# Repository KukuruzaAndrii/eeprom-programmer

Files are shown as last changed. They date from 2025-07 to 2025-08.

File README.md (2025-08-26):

## PCB design
Done in KiCad 9.0

### Scheme
[Scheme](pcb/v1/scheme/eeprom-programmer.pdf)

### PCB
Two versions of PCB placed in repo: regular and with rounded tracks.
Rounded tracks done with [mitxela plugin](https://github.com/mitxela/kicad-round-tracks)

### BOM
[Interactive BOM list](pcb/v1/bom/ibom.html)

### Gergers
For [regular pcb](pcb/v1/gerbers) and [rounded pcb](pcb/v1/gerbers-rounded)

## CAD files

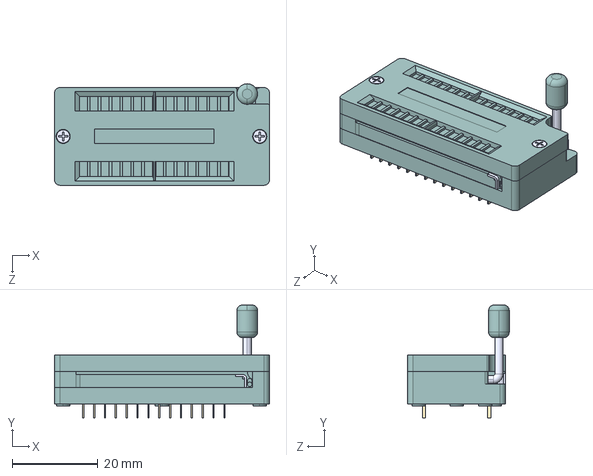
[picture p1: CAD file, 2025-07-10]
pcb/v1/Components/228_1277_00_0602J/228-1277-00-0602J.STEP
50.3 x 26.4 x 23.7 mm

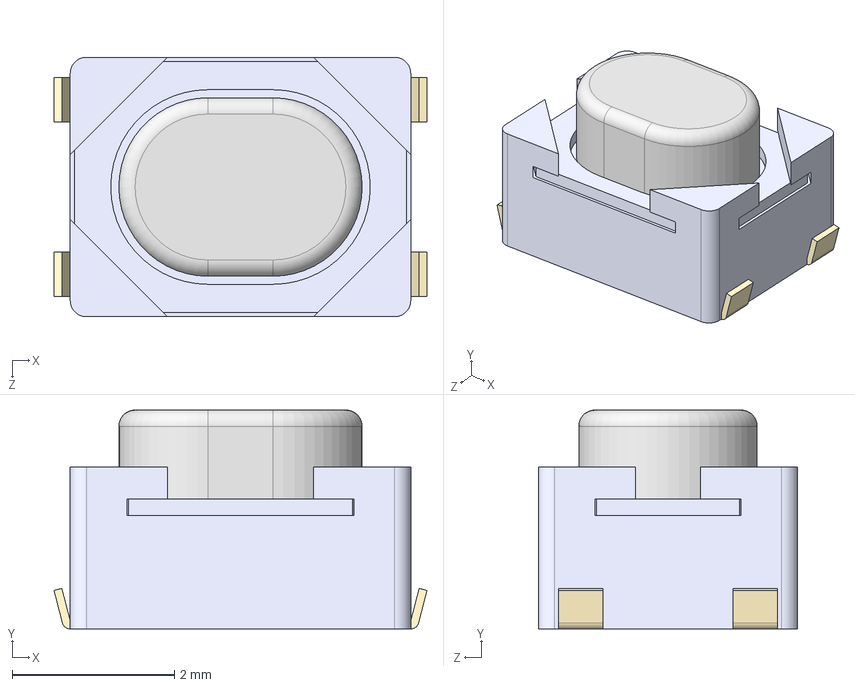
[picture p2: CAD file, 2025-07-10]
pcb/v1/Components/PTS810SJM250SMTR_LFS/PTS810SJM250SMTR LFS.STEP
4.60 x 2.70 x 3.20 mm

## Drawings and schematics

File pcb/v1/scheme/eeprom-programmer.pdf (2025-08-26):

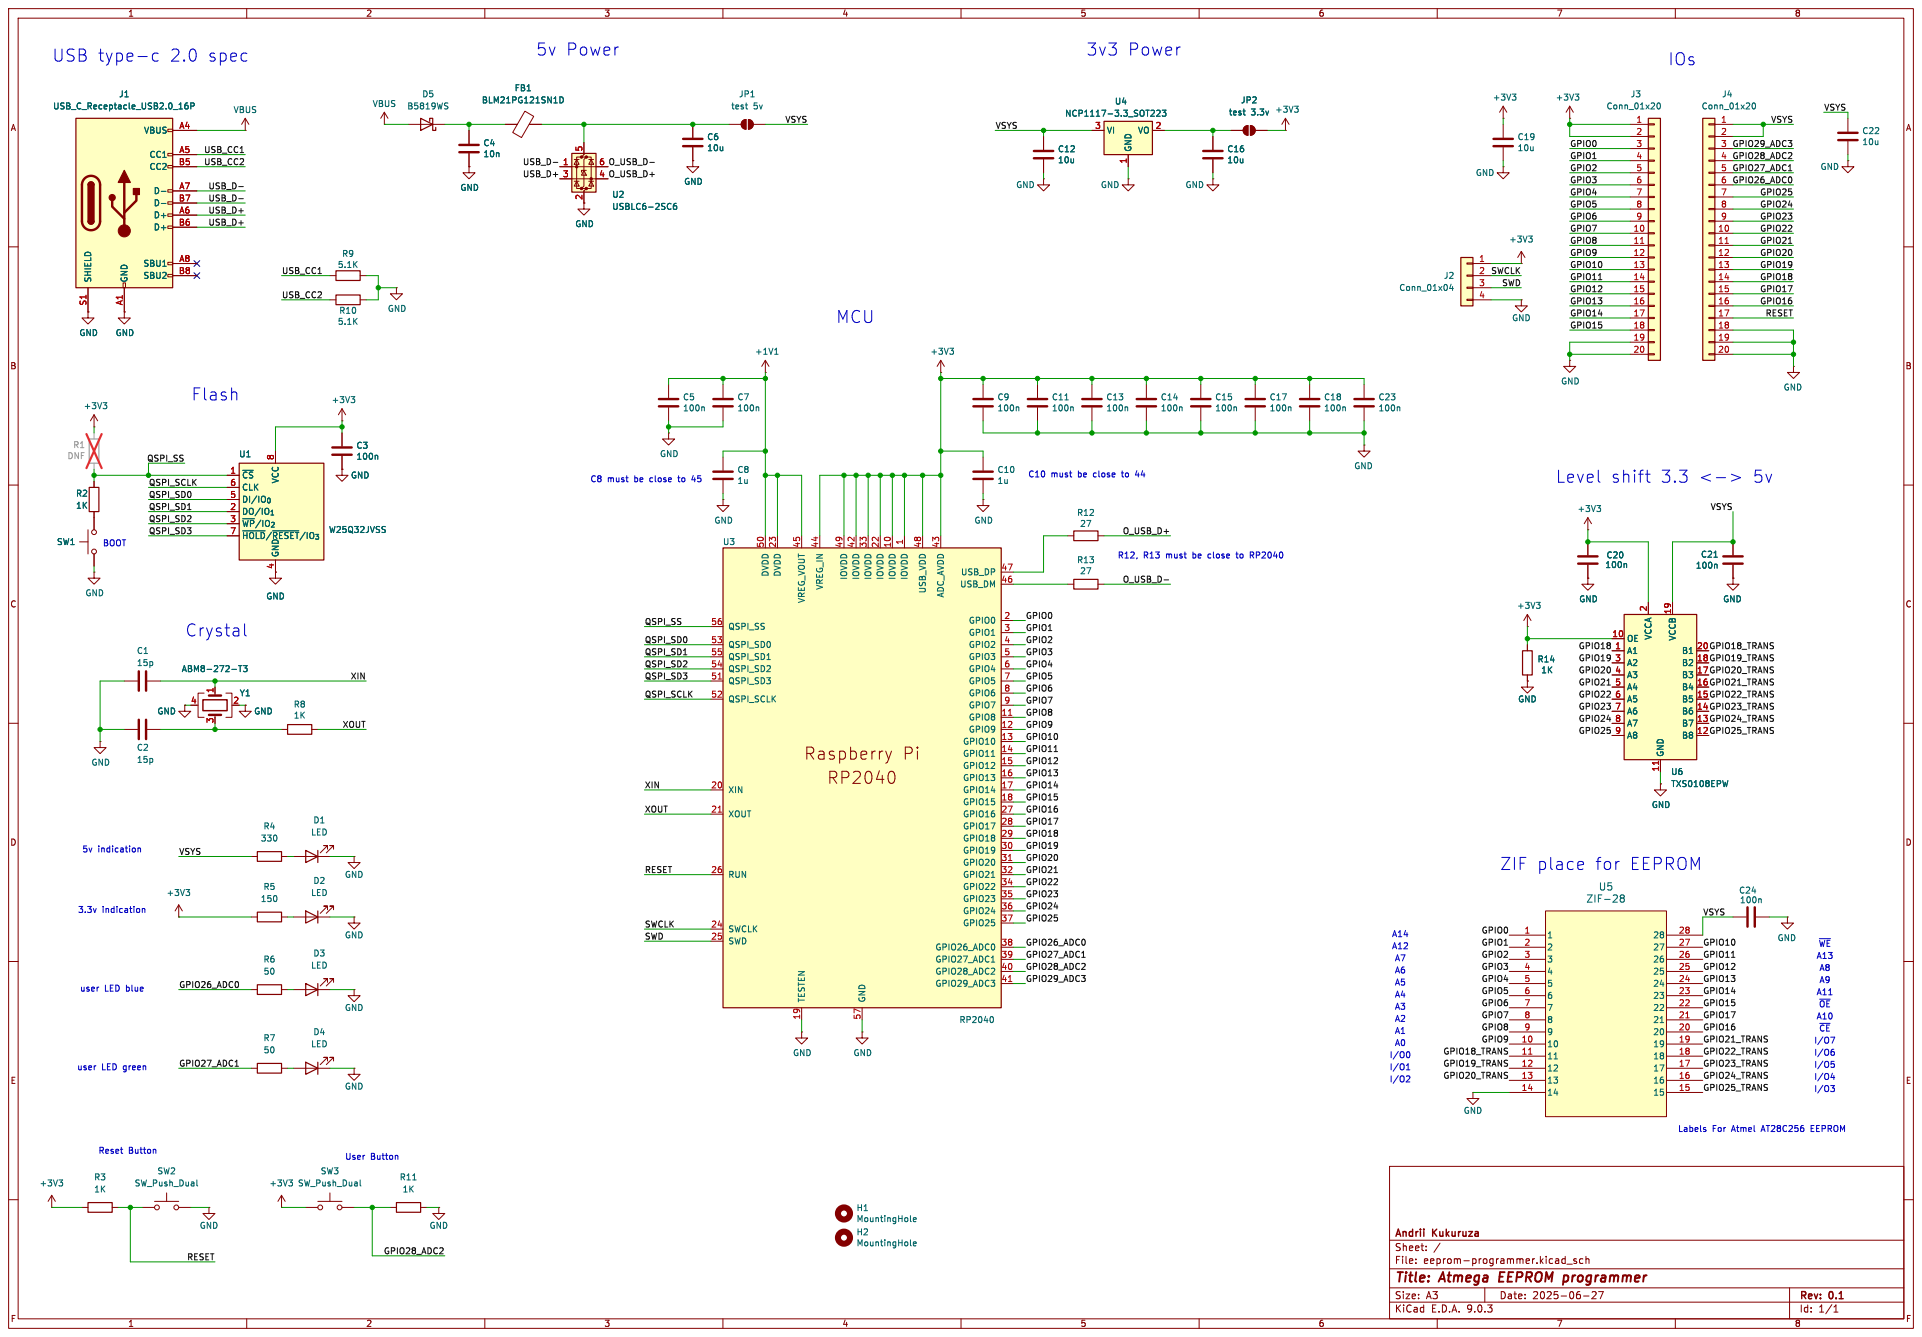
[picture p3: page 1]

3 GND GND GND GND
Crystal

I/O1 User Button Reset Button

Labels For Atmel AT28C256 EEPROM

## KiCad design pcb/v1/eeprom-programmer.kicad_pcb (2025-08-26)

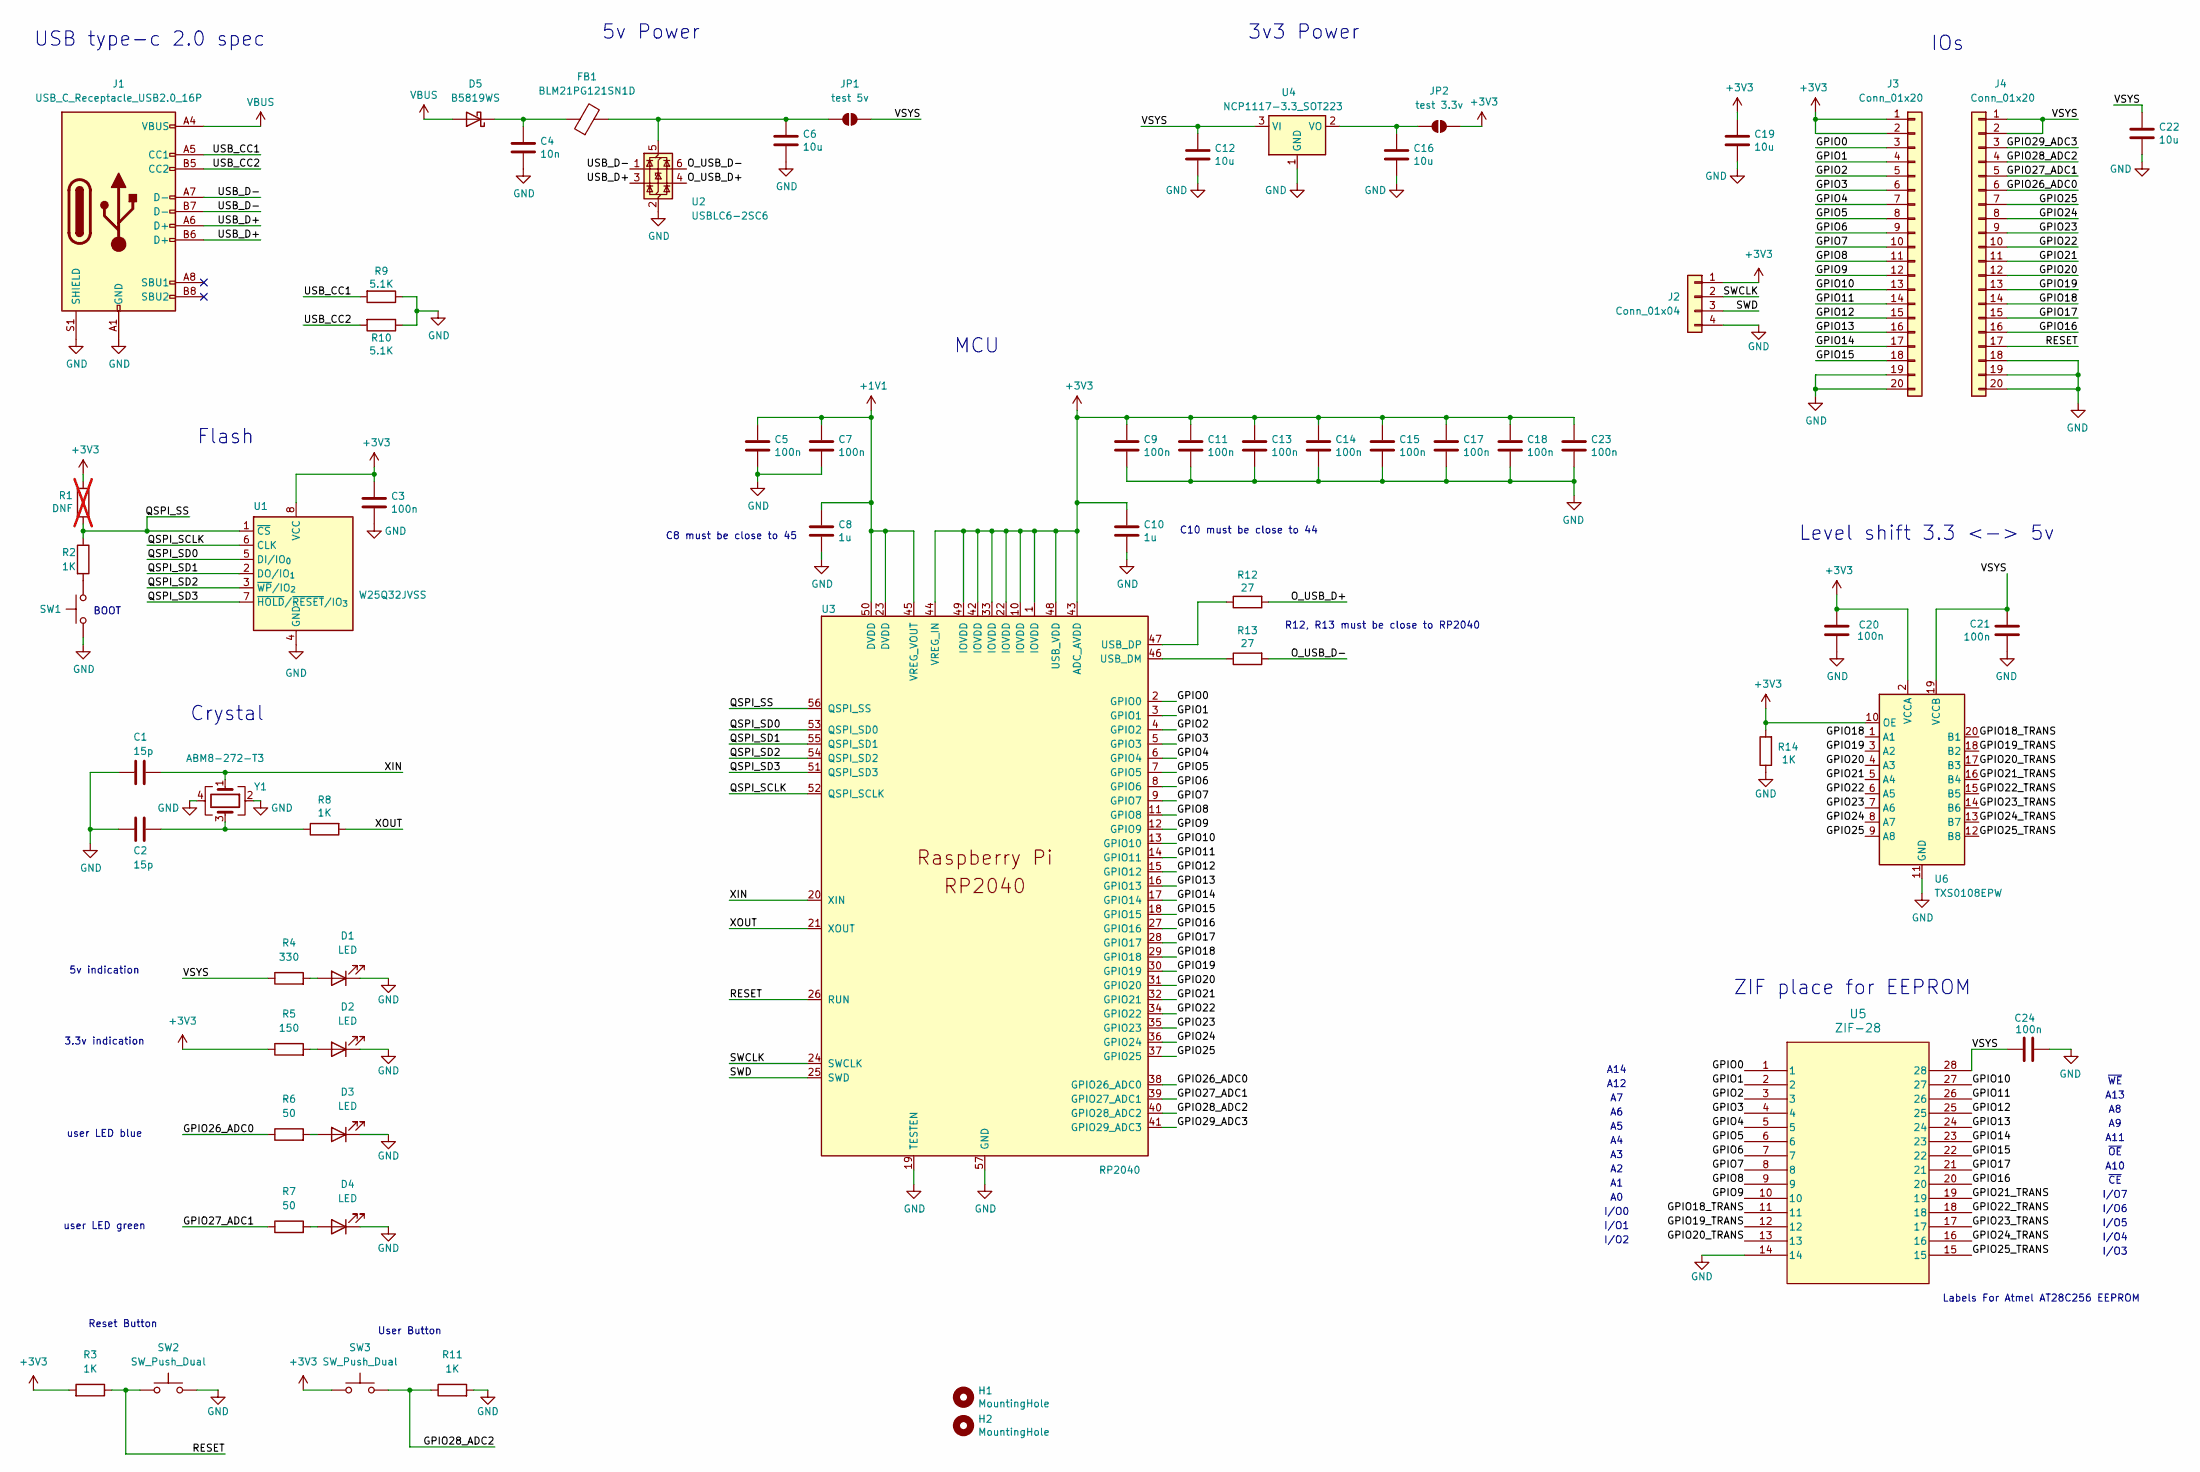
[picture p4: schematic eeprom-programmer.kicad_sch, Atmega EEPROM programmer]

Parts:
C1, C2: 15p; C_0603_1608Metric_Pad1.08x0.95mm_HandSolder
C3, C5, C7, C9, C11, C13, C14, C15, C17, C18, C20, C21, C23, C24: 100n; C_0603_1608Metric_Pad1.08x0.95mm_HandSolder
C4: 10n; C_0603_1608Metric_Pad1.08x0.95mm_HandSolder
C6, C12, C16, C19, C22: 10u; C_0603_1608Metric_Pad1.08x0.95mm_HandSolder
C8, C10: 1u; C_0603_1608Metric_Pad1.08x0.95mm_HandSolder
D1, D2, D3, D4: LED; LED_0603_1608Metric_Pad1.05x0.95mm_HandSolder
D5: B5819WS; D_SOD-323_HandSoldering
FB1: BLM21PG121SN1D; L_0805_2012Metric_Pad1.05x1.20mm_HandSolder
H1, H2: MountingHole; MountingHole_2.7mm_M2.5
J1: USB_C_Receptacle_USB2.0_16P; USB_C_Receptacle_GCT_USB4105-xx-A_16P_TopMnt_Horizontal
J2: Conn_01x04; PinHeader_1x04_P2.54mm_Vertical
J3, J4: Conn_01x20; PinHeader_1x20_P2.54mm_Vertical
JP1: test 5v; SolderJumper-2_P1.3mm_Open_RoundedPad1.0x1.5mm
JP2: test 3.3v; SolderJumper-2_P1.3mm_Open_RoundedPad1.0x1.5mm
R1: DNF; R_0603_1608Metric_Pad0.98x0.95mm_HandSolder; not fitted
R2, R3, R8, R11, R14: 1K; R_0603_1608Metric_Pad0.98x0.95mm_HandSolder
R4: 330; R_0603_1608Metric_Pad0.98x0.95mm_HandSolder
R5: 150; R_0603_1608Metric_Pad0.98x0.95mm_HandSolder
R6, R7: 50; R_0603_1608Metric_Pad0.98x0.95mm_HandSolder
R9, R10: 5.1K; R_0603_1608Metric_Pad0.98x0.95mm_HandSolder
R12, R13: 27; R_0603_1608Metric_Pad0.98x0.95mm_HandSolder
SW1, SW2, SW3: SW_Push_Dual; SW_SPST_PTS810
U1: W25Q32JVSS; SOIC-8_5.3x5.3mm_P1.27mm
U2: USBLC6-2SC6; SOT-23-6_Handsoldering
U3: RP2040; RP2040-QFN-56
U4: NCP1117-3.3_SOT223; SOT-223-3_TabPin2
U5: ZIF-28; DIP_Socket-28_W11.9_W12.7_W15.24_W17.78_W18.5_3M_228-1277-0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
U6: TXS0108EPW; TSSOP-20_4.4x6.5mm_P0.65mm
Y1: ABM8-272-T3; Crystal_SMD_Abracon_ABM8G-4Pin_3.2x2.5mm

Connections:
+1V1: C5.1, C7.1, C8.1, U3.23 (DVDD), U3.45 (VREG_VOUT), U3.50 (DVDD)
+3V3: C3.1, C9.1, C10.1, C11.1, C13.1, C14.1, C15.1, C17.1, C18.1, C19.1, C20.2, C23.1, J2.1, J3.1, J3.2, JP2.2 (B), R1.1, R3.2, R5.1, R14.2, SW3.1, U1.8 (VCC), U3.1 (IOVDD), U3.10 (IOVDD), U3.22 (IOVDD), U3.33 (IOVDD), U3.42 (IOVDD), U3.43 (ADC_AVDD), U3.44 (VREG_IN), U3.48 (USB_VDD), U3.49 (IOVDD), U6.2 (VCCA), U6.10 (OE)
/GPIO0: J3.3, U3.2 (GPIO0), U5.1
/GPIO1: J3.4, U3.3 (GPIO1), U5.2
/GPIO2: J3.5, U3.4 (GPIO2), U5.3
/GPIO3: J3.6, U3.5 (GPIO3), U5.4
/GPIO4: J3.7, U3.6 (GPIO4), U5.5
/GPIO5: J3.8, U3.7 (GPIO5), U5.6
/GPIO6: J3.9, U3.8 (GPIO6), U5.7
/GPIO7: J3.10, U3.9 (GPIO7), U5.8
/GPIO8: J3.11, U3.11 (GPIO8), U5.9
/GPIO9: J3.12, U3.12 (GPIO9), U5.10
/GPIO10: J3.13, U3.13 (GPIO10), U5.27
/GPIO11: J3.14, U3.14 (GPIO11), U5.26
/GPIO12: J3.15, U3.15 (GPIO12), U5.25
/GPIO13: J3.16, U3.16 (GPIO13), U5.24
/GPIO14: J3.17, U3.17 (GPIO14), U5.23
/GPIO15: J3.18, U3.18 (GPIO15), U5.22
/GPIO16: J4.16, U3.27 (GPIO16), U5.20
/GPIO17: J4.15, U3.28 (GPIO17), U5.21
/GPIO18: J4.14, U3.29 (GPIO18), U6.1 (A1)
/GPIO18_TRANS: U5.11, U6.20 (B1)
/GPIO19: J4.13, U3.30 (GPIO19), U6.3 (A2)
/GPIO19_TRANS: U5.12, U6.18 (B2)
/GPIO20: J4.12, U3.31 (GPIO20), U6.4 (A3)
/GPIO20_TRANS: U5.13, U6.17 (B3)
/GPIO21: J4.11, U3.32 (GPIO21), U6.5 (A4)
/GPIO21_TRANS: U5.19, U6.16 (B4)
/GPIO22: J4.10, U3.34 (GPIO22), U6.6 (A5)
/GPIO22_TRANS: U5.18, U6.15 (B5)
/GPIO23: J4.9, U3.35 (GPIO23), U6.7 (A6)
/GPIO23_TRANS: U5.17, U6.14 (B6)
/GPIO24: J4.8, U3.36 (GPIO24), U6.8 (A7)
/GPIO24_TRANS: U5.16, U6.13 (B7)
/GPIO25: J4.7, U3.37 (GPIO25), U6.9 (A8)
/GPIO25_TRANS: U5.15, U6.12 (B8)
/GPIO26_ADC0: J4.6, R6.1, U3.38 (GPIO26_ADC0)
/GPIO27_ADC1: J4.5, R7.1, U3.39 (GPIO27_ADC1)
/GPIO28_ADC2: J4.4, R11.1, SW3.2, U3.40 (GPIO28_ADC2)
/GPIO29_ADC3: J4.3, U3.41 (GPIO29_ADC3)
/O_USB_D+: R12.2, U2.4 (I/O2)
/O_USB_D-: R13.2, U2.6 (I/O1)
/QSPI_SCLK: U1.6 (CLK), U3.52 (QSPI_SCLK)
/QSPI_SD0: U1.5 (DI/IO_{0}), U3.53 (QSPI_SD0)
/QSPI_SD1: U1.2 (DO/IO_{1}), U3.55 (QSPI_SD1)
/QSPI_SD2: U1.3 (~WP/IO_{2}), U3.54 (QSPI_SD2)
/QSPI_SD3: U1.7 (~HOLD/~RESET/IO_{3}), U3.51 (QSPI_SD3)
/QSPI_SS: R1.2, R2.1, U1.1 (~CS), U3.56 (QSPI_SS)
/RESET: J4.17, R3.1, SW2.1, U3.26 (RUN)
/SWCLK: J2.2, U3.24 (SWCLK)
/SWD: J2.3, U3.25 (SWD)
/USB_CC1: J1.A5 (CC1), R9.2
/USB_CC2: J1.B5 (CC2), R10.2
/USB_D+: J1.A6 (D+), J1.B6 (D+), U2.3 (I/O2)
/USB_D-: J1.A7 (D-), J1.B7 (D-), U2.1 (I/O1)
/VSYS: C12.1, C21.1, C22.1, C24.1, J4.1, J4.2, JP1.2 (B), R4.1, U4.3 (VI), U5.28, U6.19 (VCCB)
/XIN: C1.2, U3.20 (XIN), Y1.1
/XOUT: R8.2, U3.21 (XOUT)
GND: C1.1, C2.2, C3.2, C4.2, C5.2, C6.2, C7.2, C8.2, C9.2, C10.2, C11.2, C12.2, C13.2, C14.2, C15.2, C16.2, C17.2, C18.2, C19.2, C20.1, C21.2, C22.2, C23.2, C24.2, D1.1 (K), D2.1 (K), D3.1 (K), D4.1 (K), J1.A1 (GND), J1.A12 (GND), J1.B1 (GND), J1.B12 (GND), J1.S1 (SHIELD), J2.4, J3.19, J3.20, J4.18, J4.19, J4.20, R9.1, R10.1, R11.2, R14.1, SW1.1, SW2.2, U1.4 (GND), U2.2 (GND), U3.19 (TESTEN), U3.57 (GND), U4.1 (GND), U5.14, U6.11 (GND), Y1.2, Y1.4
unnamed: C2.1, R8.1, Y1.3
unnamed: D1.2 (A), R4.2
unnamed: D2.2 (A), R5.2
unnamed: D3.2 (A), R6.2
unnamed: D4.2 (A), R7.2
unnamed: C4.1, D5.1 (K), FB1.1
unnamed: C6.1, FB1.2, JP1.1 (A), U2.5 (VBUS)
unnamed: C16.1, JP2.1 (A), U4.2 (VO)
unnamed: R2.2, SW1.2
unnamed: R13.1, U3.46 (USB_DM)
unnamed: R12.1, U3.47 (USB_DP)
VBUS: D5.2 (A), J1.A4 (VBUS), J1.A9 (VBUS), J1.B4 (VBUS), J1.B9 (VBUS)

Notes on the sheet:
A11
A10
Labels For Atmel AT28C256 EEPROM
IOs
5v Power
~{CE}
3v3 Power
Crystal
I/O2
Level shift 3.3 <-> 5v
MСU
C8 must be close to 45
I/O3
I/O4
I/O6
A12
USB type-c 2.0 spec
user LED green
I/O5
User Button
BOOT
C10 must be close to 44
5v indication
user LED blue
A13
I/O1
I/O0
3.3v indication
Reset Button
R12, R13 must be close to RP2040
ZIF place for EEPROM
A14
~{OE}
Flash
I/O7
~{WE}

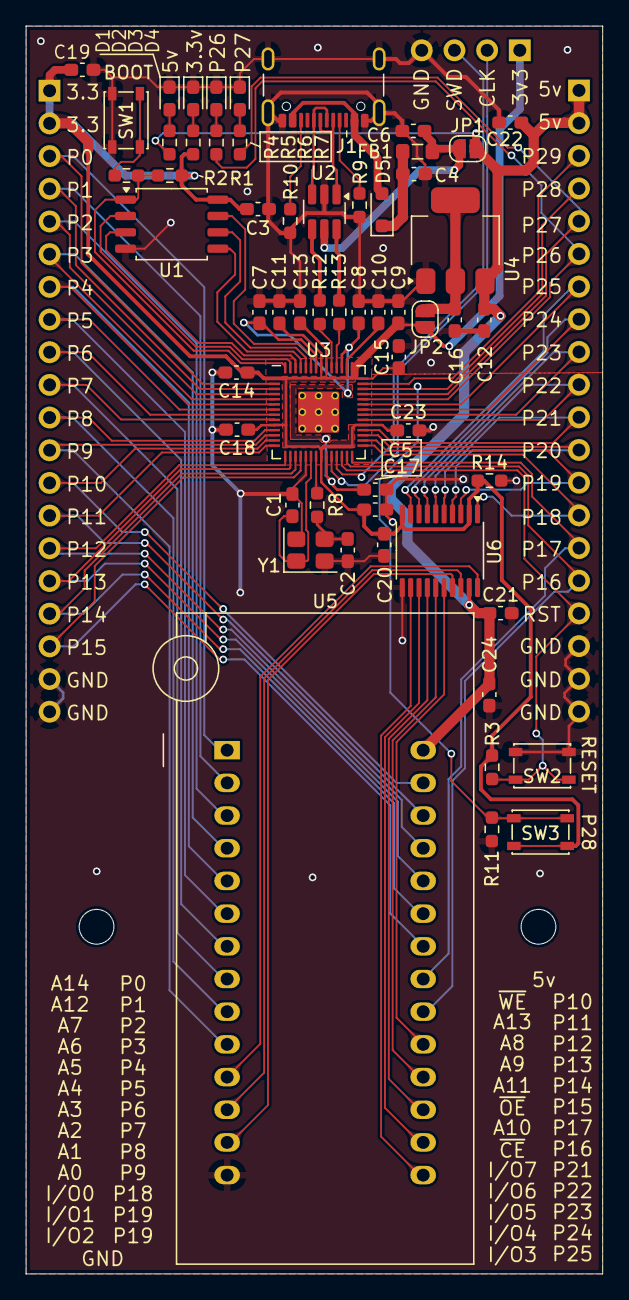
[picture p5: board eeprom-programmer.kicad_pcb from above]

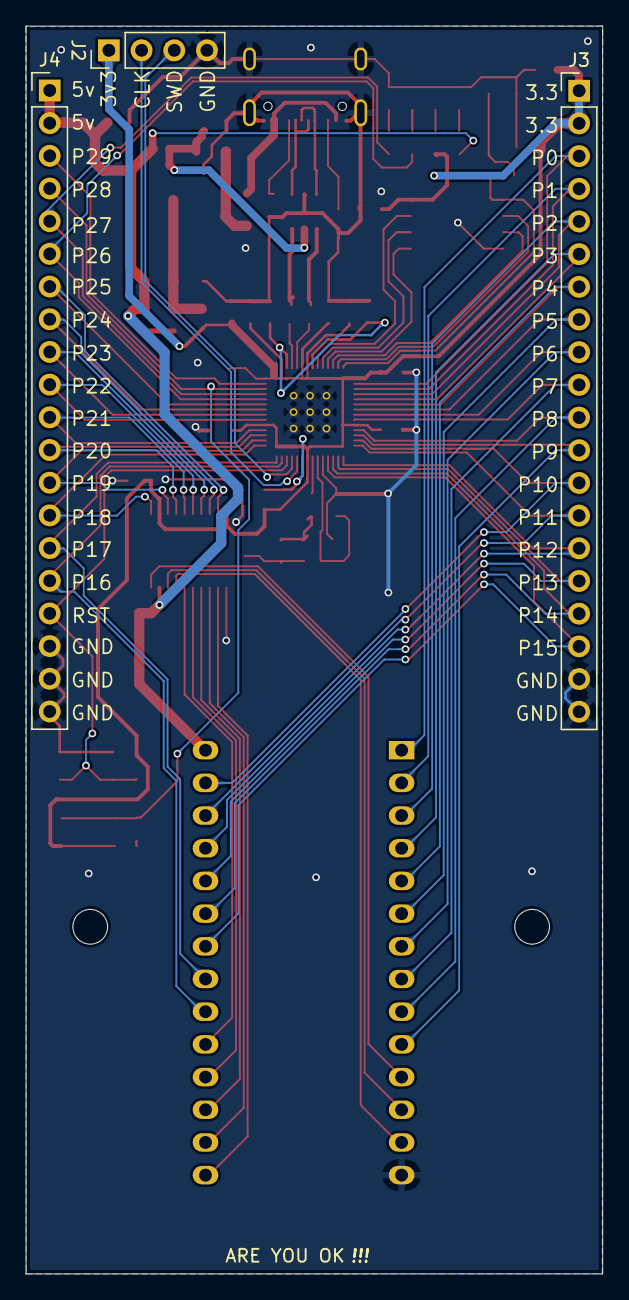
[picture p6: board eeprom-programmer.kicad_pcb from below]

Board: 2 copper layers, 44.8 x 97.0 mm, 62 parts (3 on the bottom side), 71 nets.

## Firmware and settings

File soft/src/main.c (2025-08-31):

#include <stdio.h>
#include "pico/stdlib.h"
#include "hardware/gpio.h"
#include "pico/binary_info.h"

const uint LED_PIN = 26;

int main() {

	bi_decl(bi_program_description("This is a test binary."));
	bi_decl(bi_1pin_with_name(LED_PIN, "On-board LED"));

	stdio_init_all();

	gpio_init(LED_PIN);
	gpio_set_dir(LED_PIN, GPIO_OUT);
	gpio_init(27);
	gpio_set_dir(27, GPIO_OUT);

	while (1) {
		gpio_put(LED_PIN, 0);
		gpio_put(27, 1);
		sleep_ms(250);
		gpio_put(LED_PIN, 1);
		gpio_put(27, 0);
		puts("Hello World\n");
		sleep_ms(1000);
	}
}

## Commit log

2025-07-10 init; add pcb v1
    [228-1277-00-0602J.STEP, PTS810SJM250SMTR LFS.STEP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]
2025-08-26 fix 2 mixed up labels; update output files; add pcb with rounded labels
    [eeprom-programmer-rounded-B_Cu.gbr, eeprom-programmer-rounded-B_Mask.gbr, eeprom-programmer-rounded-B_Silkscreen.gbr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]
